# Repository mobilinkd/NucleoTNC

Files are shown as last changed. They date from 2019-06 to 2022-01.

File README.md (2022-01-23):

# NucleoTNC Firmware

Source code for STM32L432KC Nucleo32-based TNC (PCB & breadboard version).

http://www.mobilinkd.com/2019/06/24/nucleotnc/

# Building the Firmware

Use Eclipse with CDT and the GNU MCU Eclipse plugins.

If you are porting this to another build platform, you will need to
build the firmware using the same compiler and linker options.  As
with most firmware projects, there is a linker script with defines
the memory layout for for the Flash and SRAM.

## Blaze Dependency

There is a new dependency as of 2.4.3 with the addition of the Kalman
filter.  The firmware has a dependency on the Blaze C++ math library.

    mkdir blaze
    ln -s /usr/include/blaze blaze/

This also requires (for now) that the firmware be built with exceptions
enabled.

## Example GCC Command-line

Below are example compilation and linking lines for reference:

    arm-none-eabi-g++ -mcpu=cortex-m4 -mthumb -mfloat-abi=softfp -mfpu=fpv4-sp-d16 -O2 -fmessage-length=0 -fsigned-char -ffunction-sections -fdata-sections -fno-inline-functions -fsingle-precision-constant -fstack-usage -fstrict-aliasing -ffast-math -Wall -Wextra -Wlogical-op -Wfloat-equal -g -D__FPU_PRESENT=1 -DUSE_HAL_DRIVER -DARM_MATH_CM4 -DSTM32L432xx -D__weak=__attribute__((weak)) -DNUCLEOTNC=1 -I../Inc -I../Drivers/STM32L4xx_HAL_Driver/Inc -I/home/rob/workspace/Nucleo_L432KC_TNC/Inc -I/home/rob/workspace/Nucleo_L432KC_TNC/Drivers/STM32L4xx_HAL_Driver/Inc -I/home/rob/workspace/Nucleo_L432KC_TNC/Drivers/CMSIS/Include -I/home/rob/workspace/Nucleo_L432KC_TNC/Drivers/CMSIS/Device/ST/STM32L4xx/Include -I/home/rob/workspace/Nucleo_L432KC_TNC/Middlewares/Third_Party/FreeRTOS/Source/include -I/home/rob/workspace/Nucleo_L432KC_TNC/Middlewares/Third_Party/FreeRTOS/Source/CMSIS_RTOS -I/home/rob/workspace/Nucleo_L432KC_TNC/Middlewares/Third_Party/FreeRTOS/Source/portable/GCC/ARM_CM4F -I/home/rob/workspace/Nucleo_L432KC_TNC/TNC -I/usr/arm-none-eabi/include -std=gnu++1z -fabi-version=9 -fno-exceptions -fno-rtti -fno-use-cxa-atexit -fno-threadsafe-statics -Wno-register -c -o TNC/HdlcFrame.o ../TNC/HdlcFrame.cpp 
    arm-none-eabi-g++ -mcpu=cortex-m4 -mthumb -mfloat-abi=softfp -mfpu=fpv4-sp-d16 -O2 -fmessage-length=0 -fsigned-char -ffunction-sections -fdata-sections -fno-inline-functions -fsingle-precision-constant -fstack-usage -fstrict-aliasing -ffast-math -Wall -Wextra -Wlogical-op -Wfloat-equal -g -T /home/rob/workspace/Nucleo_L432KC_TNC/STM32L432KC_FLASH.ld -Xlinker --gc-sections -Wl,-Map,firmware.map --specs=nano.specs -o firmware.elf Drivers/STM32L4xx_HAL_Driver/Src/stm32l4xx_hal.o Drivers/STM32L4xx_HAL_Driver/Src/stm32l4xx_hal_adc.o Drivers/STM32L4xx_HAL_Driver/Src/stm32l4xx_hal_adc_ex.o Drivers/STM32L4xx_HAL_Driver/Src/stm32l4xx_hal_cortex.o Drivers/STM32L4xx_HAL_Driver/Src/stm32l4xx_hal_crc.o Drivers/STM32L4xx_HAL_Driver/Src/stm32l4xx_hal_crc_ex.o Drivers/STM32L4xx_HAL_Driver/Src/stm32l4xx_hal_dac.o Drivers/STM32L4xx_HAL_Driver/Src/stm32l4xx_hal_dac_ex.o Drivers/STM32L4xx_HAL_Driver/Src/stm32l4xx_hal_dma.o Drivers/STM32L4xx_HAL_Driver/Src/stm32l4xx_hal_dma_ex.o Drivers/STM32L4xx_HAL_Driver/Src/stm32l4xx_hal_flash.o Drivers/STM32L4xx_HAL_Driver/Src/stm32l4xx_hal_flash_ex.o Drivers/STM32L4xx_HAL_Driver/Src/stm32l4xx_hal_flash_ramfunc.o Drivers/STM32L4xx_HAL_Driver/Src/stm32l4xx_hal_gpio.o Drivers/STM32L4xx_HAL_Driver/Src/stm32l4xx_hal_i2c.o Drivers/STM32L4xx_HAL_Driver/Src/stm32l4xx_hal_i2c_ex.o Drivers/STM32L4xx_HAL_Driver/Src/stm32l4xx_hal_opamp.o Drivers/STM32L4xx_HAL_Driver/Src/stm32l4xx_hal_opamp_ex.o Drivers/STM32L4xx_HAL_Driver/Src/stm32l4xx_hal_pwr.o Drivers/STM32L4xx_HAL_Driver/Src/stm32l4xx_hal_pwr_ex.o Drivers/STM32L4xx_HAL_Driver/Src/stm32l4xx_hal_rcc.o Drivers/STM32L4xx_HAL_Driver/Src/stm32l4xx_hal_rcc_ex.o Drivers/STM32L4xx_HAL_Driver/Src/stm32l4xx_hal_rng.o Drivers/STM32L4xx_HAL_Driver/Src/stm32l4xx_hal_rtc.o Drivers/STM32L4xx_HAL_Driver/Src/stm32l4xx_hal_rtc_ex.o Drivers/STM32L4xx_HAL_Driver/Src/stm32l4xx_hal_tim.o Drivers/STM32L4xx_HAL_Driver/Src/stm32l4xx_hal_tim_ex.o Drivers/STM32L4xx_HAL_Driver/Src/stm32l4xx_hal_uart.o Drivers/STM32L4xx_HAL_Driver/Src/stm32l4xx_hal_uart_ex.o Middlewares/Third_Party/FreeRTOS/Source/CMSIS_RTOS/cmsis_os.o Middlewares/Third_Party/FreeRTOS/Source/croutine.o Middlewares/Third_Party/FreeRTOS/Source/event_groups.o Middlewares/Third_Party/FreeRTOS/Source/list.o Middlewares/Third_Party/FreeRTOS/Source/portable/GCC/ARM_CM4F/port.o Middlewares/Third_Party/FreeRTOS/Source/portable/MemMang/heap_4.o Middlewares/Third_Party/FreeRTOS/Source/queue.o Middlewares/Third_Party/FreeRTOS/Source/tasks.o Middlewares/Third_Party/FreeRTOS/Source/timers.o Src/arm_fir_f32.o Src/arm_fir_fast_q15.o Src/arm_fir_init_f32.o Src/arm_fir_init_q15.o Src/arm_fir_interpolate_init_q15.o Src/arm_fir_interpolate_q15.o Src/arm_offset_q15.o Src/arm_q15_to_float.o Src/freertos.o Src/main.o Src/stm32l4xx_hal_msp.o Src/stm32l4xx_hal_timebase_TIM.o Src/stm32l4xx_it.o Src/system_stm32l4xx.o TNC/AFSKModulator.o TNC/AFSKTestTone.o TNC/Afsk1200Demodulator.o TNC/AfskDemodulator.o TNC/AudioInput.o TNC/AudioLevel.o TNC/DCD.o TNC/Demodulator.o TNC/FilterCoefficients.o TNC/Fsk9600Demodulator.o TNC/Fsk9600Modulator.o TNC/Goertzel.o TNC/Golay24.o TNC/HdlcDecoder.o TNC/HdlcFrame.o TNC/IOEventTask.o TNC/Kiss.o TNC/KissHardware.o TNC/KissTask.o TNC/LEDIndicator.o TNC/Log.o TNC/M17.o TNC/M17Demodulator.o TNC/M17Encoder.o TNC/M17Modulator.o TNC/ModulatorTask.o TNC/NullPort.o TNC/PortInterface.o TNC/SerialPort.o newlib/_exit.o newlib/_sbrk.o newlib/_syscalls.o startup/startup_stm32l432xx.o 

All of the macros defined on the compiler line are important in order
to properly build the firmware.

# Installing firmware

Firmware can be installed via the storage interface (drag & drop), the
on-board ST/LINK port, or via USB DFU.

## Drag & Drop

For the NucleoTNC, the easiest way to install firmware is to copy the
firmware file to the TNC directly.  The NucleoTNC will show up as a storage
device when plugged in.  Just copy the firmware.bin file into the shared
folder.  The firmware will automatically install, the NucleoTNC will reset,
and the new firmware will be running.

## ST/Link

The ST/Link port is a debug port exposed by the NucleoTNC.  It can be used
by Eclipse and other IDEs to directly upload the firmware to the TNC.

## USB DFU

 1. Download the STM32CubeProgrammer.
    https://s3.amazonaws.com/mobilinkd/en.stm32cubeprog-1.4.0.zip
    This programmer will work on Linux, OS X, and Windows.

 2. Download the ELF file from the release (or that you have built from source).

 3. Run the STM32CubeProgrammer from the command-line. (Replace "firmware.elf" with the appropriate firmware filename.)

    ./STM32_Programmer_CLI -c port=USB1 -d firmware.elf -v -g 0x8000000

 4. When that is complete, the NucleoTNC will restart with the new firmware.

----

## Important Note
If you regenerate the STM32 code, please note that the LL ADC driver in
the 1.12.0 version of the HAL driver is buggy.

   Drivers/STM32L4xx_HAL_Driver/Inc/stm32l4xx_ll_adc.h

This file has been modified to address the defect.  If it is replaced by
STM32CubeMX, please ensure that the defect has been fixed.

Details of the defect are available [on the ST community site](https://community.st.com/s/question/0D50X00009bLP0eSAG/adc-init-bug-with-optimization-o1-stm32l4 ADC init bug with optimization >= -O1).

----

## TNC Build Instructions

Please go here: [TNC Build Instructions](Build/NucleoTNC.ipynb)

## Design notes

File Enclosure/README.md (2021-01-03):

# NucleoTNC Enclosure

This work is licensed under a
<a rel="license" href="http://creativecommons.org/licenses/by-sa/4.0/">
Creative Commons Attribution-ShareAlike 4.0 International License</a>.
<a rel="license" href="http://creativecommons.org/licenses/by-sa/4.0/">
</a><br />

Please attribute the work to *Rob Riggs, WX9O, Mobilinkd LLC*.

This is an enclosure for the NucleoTNC PCB.  It uses a two-part extruded
aluminum enclosure, SZOMK AK-C-C15 (26*71*100mm).  This folder contains
the faceplates for the enclosure.  These are KiCAD components for the
front and read faceplates.  It also includes a spacer designed to raise
the Nucleo32 board from the PCB so that it will fit into the enclosure.

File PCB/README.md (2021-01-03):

# NucleoTNC PCB

This directory contains the KiCAD files for the Nucleo TNC PCB.  This is a PCB
for the [NucleoTNC breadboard project](http://www.mobilinkd.com/2019/06/24/nucleotnc/).

The design goal was to allow experimenters to take their breadboard project and give
it a more permanent home on a real printed circuit board.

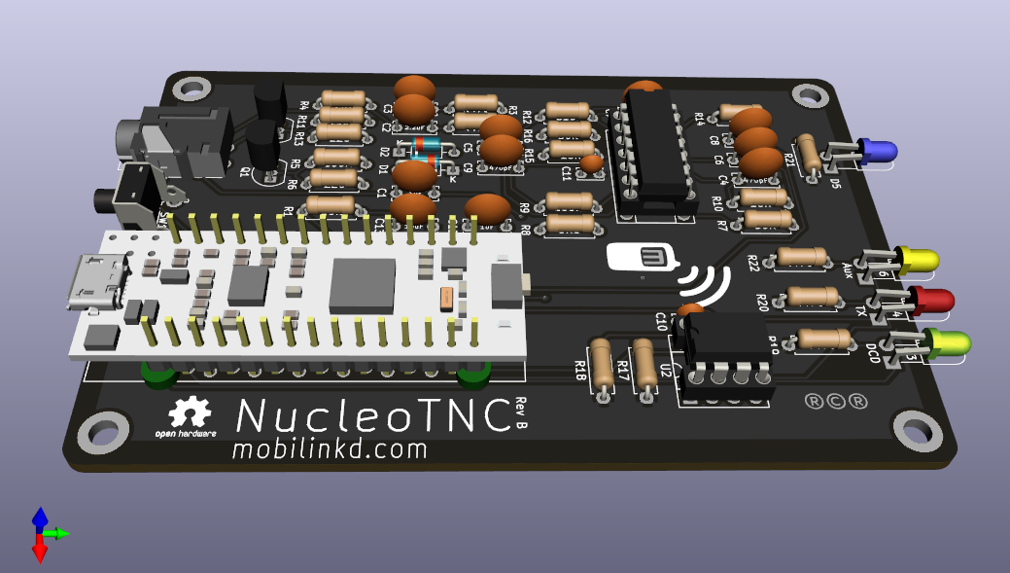
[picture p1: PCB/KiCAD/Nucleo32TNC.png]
NucleoTNC PCB


This PCB is designed to fit in the [enclosure](../Enclosure/README.md) that is also
available in this repository.

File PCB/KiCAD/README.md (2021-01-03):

# NucleoTNC PCB

This work is licensed under a
<a rel="license" href="http://creativecommons.org/licenses/by-sa/4.0/">
Creative Commons Attribution-ShareAlike 4.0 International License</a>.
<a rel="license" href="http://creativecommons.org/licenses/by-sa/4.0/">
</a><br />

Please attribute the work to *Rob Riggs, WX9O, Mobilinkd LLC*.

This directory contains the KiCAD files for the Nucleo TNC printed circuit
board (PCB).  This is a PCB for the [NucleoTNC breadboard project](http://www.mobilinkd.com/2019/06/24/nucleotnc/).

NucleoTNC PCB

The design goal is to allow experimenters to take their breadboard project
and give it a more permanent home on a real printed circuit board.

This PCB is designed to fit in the [enclosure](../../Enclosure/README.md) that is
also available in this repository.

Please refer to the [NucleoTNC breadboard project](https://nbviewer.jupyter.org/github/mobilinkd/NucleoTNC/blob/master/Build/NucleoTNC.ipynb)
project for in-depth discussion of the design and theory of operation.  We are
only going to cover briefly the design differences below, then provide the full
bill of materials (BOM) required to build the TNC.

This repository also contains the open source firmware for the TNC.  The
Mobilinkd project on Github contains numerous other resources, including a
Python-based configuration program.

These PCBs can be purchased directly from the mobilinkd store.

https://store.mobilinkd.com/collections/kits

## Breadboard Differences

This section covers the differences between the NucleoTNC breadboard project
and the PCB version.  The schematic is presented below.

There are a few small differences in design.

The one necessary change was to the 3.5mm jack.  The breadboard module is
inappropriate for a PCB design.  The PCB uses a CUI SJ-43515TS or SJ-43514
jack.  Discovered after this choice was made is that CUI uses the same model
number for both a through-hole component and a surface mount component.  For
this project you will need the through-hole part.

IC sockets for the quad op-amp and EEPROM are recommended.  Insert the ICs
into the sockets rather than soldering these components directly on the PCB.

There are two additional LEDs on the PCB.  One indicates power.  The other
is there as an auxilliary indicator and is currently unused.  These exist
because the power LED and auxilliary LED on the Nucleo32 board are hidden
when the PCB is mounted in an enclosure.  Each require a 470 Ohm resistor.

There is an external reset button.  This is because the reset switch on the
TNC is inaccessible when mounted in an enclosure.  The reset button is a
C&K PTS645VL58-2 LFS.

And there are two additional capacitors on the power plane for added
decoupling.  These are not strictly necessary.

We have changed the input coupling capacitor from 0.22uF to 1uF to improve
the low frequency response of the TNC.  This is now recommended for the
breadboard version as well.

Included in the enclosure components is a spacer PCB.  This can be 3D-printed
rather than made out of FR-4 PCB material.  Two of these are needed to raise
the Nucleo32 board off the PCB so that it will fit in the enclosure properly.
You can see the two spacers in the rendering at the top of the page.

The through-holes for the Nucleo board on the PCB are staggered.  This allows
for a press-fit of the Nucleo board into the PCB for testing.  The Nucleo32 can
be inserted into the PCB and should work without being soldered in.  It will
likely only work for a few insertions.  And the Nucleo board should be soldered
in place before installing it into the enclosure.  If it comes out of the
PCB while power is applied, there is risk of damage to the Nucleo board and
the components on the PCB.

NucleoTNC PCB Schematic

## Bill of Materials

| Manufacturer 	| Manufacturer Part Number 	| Description 	| Quantity 	| Unit Price 	| Extended Price 	|
|---	|---	|---	|---	|---	|---	|
| CUI 	| SJ-43515TS 	| TRRS 3.5MM JACK THROUGH-HOLE  	| 1 	| 1.08 	| 1.08 	|
| Vishay Semiconductor Diodes Division 	| BAT85S-TAP 	| DIODE SCHOTTKY 30V 200MA DO35 	| 2 	| 0.38 	| 0.76 	|
| STMicroelectronics 	| NUCLEO-L432KC 	| NUCLEO-32 STM32L432KC EVAL BRD 	| 1 	| 10.99 	| 10.99 	|
| Microchip Technology 	| MCP6004-I/P 	| IC OPAMP GP 4 CIRCUIT 14DIP 	| 1 	| 0.45 	| 0.45 	|
| Microchip Technology 	| 24LC32A-I/P 	| IC EEPROM 32K I2C 400KHZ 8DIP 	| 1 	| 0.41 	| 0.41 	|
| Microchip Technology 	| 2N7000-G 	| MOSFET N-CH 60V 0.2A TO92-3 	| 2 	| 0.38 	| 0.76 	|
| Broadcom Limited 	| HLMP-1301 	| LED RED DIFFUSED T-1 T/H 	| 1 	| 0.41 	| 0.41 	|
| Broadcom Limited 	| HLMP-1503 	| LED GREEN DIFFUSED T-1 T/H 	| 1 	| 0.41 	| 0.41 	|
| Stackpole Electronics Inc 	| RNF18FTD100K 	| RES 100K OHM 1/8W 1% AXIAL 	| 3 	| 0.1 	| 0.30 	|
| Stackpole Electronics Inc 	| RNF14FTD10K0 	| RES 10K OHM 1/4W 1% AXIAL 	| 1 	| 0.1 	| 0.10 	|
| Stackpole Electronics Inc 	| RNMF14FTC510R 	| RES 510 OHM 1/4W 1% AXIAL 	| 2 	| 0.1 	| 0.20 	|
| Stackpole Electronics Inc 	| RNMF14FTC6K80 	| RES 6.8K OHM 1/4W 1% AXIAL 	| 1 	| 0.1 	| 0.10 	|
| Stackpole Electronics Inc 	| RNF14FTD470R 	| RES 470 OHM 1/4W 1% AXIAL 	| 6 	| 0.1 	| 0.60 	|
| Stackpole Electronics Inc 	| RNMF14FTC220R 	| RES 220 OHM 1/4W 1% AXIAL 	| 2 	| 0.1 	| 0.20 	|
| Stackpole Electronics Inc 	| RNMF14FTC2K20 	| RES 2.2K OHM 1/4W 1% AXIAL 	| 3 	| 0.1 	| 0.30 	|
| Stackpole Electronics Inc 	| RNMF14FTC16K0 	| RES 16K OHM 1/4W 1% AXIAL 	| 2 	| 0.1 	| 0.20 	|
| Stackpole Electronics Inc 	| RNMF14FTC30K0 	| RES 30K OHM 1/4W 1% AXIAL 	| 2 	| 0.1 	| 0.20 	|
| Vishay BC Components 	| K471J15C0GF53L2 	| CAP CER 470PF 50V C0G/NP0 RADIAL 	| 2 	| 0.22 	| 0.44 	|
| AVX Corporation 	| SR201A102JAR 	| CAP CER 1000PF 100V C0G/NP0 RAD  	| 2 	| 0.29 	| 0.58 	|
| Vishay BC Components 	| K103M15X7RF53L2 	| CAP CER 10000PF 50V X7R RADIAL 	| 1 	| 0.21 	| 0.21 	|
| AVX Corporation 	| SR215C104KAA 	| CAP CER 0.1UF 50V X7R RADIAL 	| 2 	| 0.2 	| 0.40 	|
| TDK Corporation 	| FG28X7R1A225KRT06 	| CAP CER 2.2UF 10V X7R RADIAL 	| 1 	| 0.34 	| 0.34 	|
| Broadcom Limited‎ 	| HLMP-1401 	| LED YELLOW DIFFUSED T-1 T/H | 1 	| 0.49 	| 0.49 	|
| Kingbright‎ 	| WP710A10QBC/D 	| LED BLUE CLEAR T-1 T/H | 1 	| 0.44 	| 0.44 	|
| C&K 	| PTS645VL58-2 LFS 	| SWITCH TACTILE SPST-NO 0.05A 12V 	| 1 	| 0.27 	| 0.27 	|
| TDK Corporation | FG28X7R1E105KRT06 | CAP CER 1UF 25V X7R RADIAL | 2 | 0.32 | 0.64 |
| TDK Corporation | FG24X7R1A106KRT06 | CAP CER 10UF 10V X7R RADIAL | 1 | 0.58 | 0.58 |
| On Shore Technology Inc. | ED14DT | CONN IC DIP SOCKET 14POS TIN | 1 | 0.18 | 0.18 |
| On Shore Technology Inc. | ED08DT | CONN IC DIP SOCKET 8POS TIN | 1 | 0.16 | 0.16 |

The new items are the last 6 items on the list.  There are two additional 470 Ohm resister (6 instead of 4) in the BOM.

You can explore the PCB via an [interactive BOM](https://htmlpreview.github.io/?https://github.com/mobilinkd/NucleoTNC/blob/master/PCB/KiCAD/bom/ibom.html).
Please note that it does not show the two DIP sockets.

## Equipment

You will need the following equipment to assemble, test and use the TNC.

 1. Soldering Iron
 1. Solder (preferrably 0.5mm rosin core)
 1. A digital multi-meter (DMM) with Voltage, Resistance, Continuity, Diode
    and Capacitance testing capabiility. (Something like an ANENG AN8008
    will work.)
 1. Anti-static mat and wrist strap.
 1. A micro-USB cable.
 1. A computer running Linux, OS X, or Windows 10.
 1. A 2mm hex driver or allen wrench if you are building the enclosure.

## Assembly

Assemble the items on a grounded anti-static mat.

Use the [interactive BOM](https://htmlpreview.github.io/?https://github.com/mobilinkd/NucleoTNC/blob/master/PCB/KiCAD/bom/ibom.html)
(use ctrl-click on the link to open it in another tab).  Install the items in
the order listed on the interactive BOM.  This makes it easier to solder
multiple components to the board without having them fall out, because the
BOM is sorted roughly by component height.

**The diodes, ICs, MOSFETs and Nucleo32 module are easily damaged by
electro-static discharge.  Use an anti-static wrist strap that is well-grounded
when handling the diodes, ICs, MOSFETs and Nucleo32 module, and when handling
the PCB after these items have been installed.**

When it comes to installing the two ICs, U1 and U2, install the IC sockets
only.  Install the ICs into the sockets after the reset switch has been
soldered to the board.

The final step is to install the Nucleo32 board.  Place the two spacers across
the pairs of pins on either end of the module.  It may be easier to place the
PCB on its side when inserting the module to keep the spacers from falling
off.  The pins are staggered.  It should require a little bit of force to get
the module inserted.  Once inserted, the pins should make solid contact with
the PCB -- solid enough for initial testing.

## Testing

**Note: when inserting a USB cable into the Nucleo32 module, make sure that
the USB cable does not apply any torque to the module as this can negatively
affect the press-fit connection with the PCB.**

We are going to connect the TNC to the computer via USB.  Plug the micro-USB
cable into the computer.

Insert a USB cable into the Nucleo32 module.  You should see the blue LED
light up.  This indicates that the board is powered.

You should also see a drive mounted on the computer and a USB serial port
created.

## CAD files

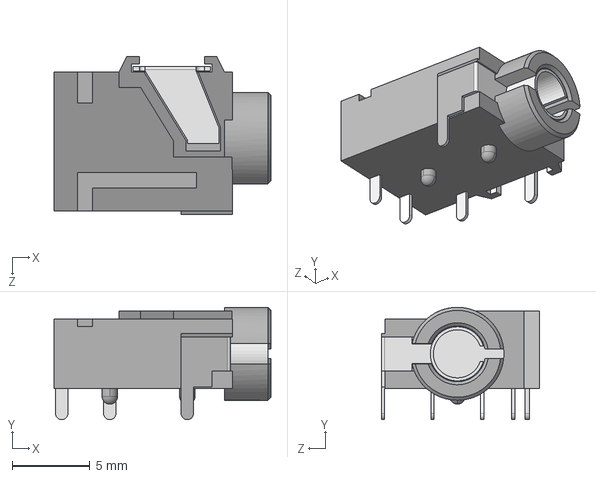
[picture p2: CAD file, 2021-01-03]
PCB/KiCAD/CUI_DEVICES_SJ-43515TS.step
14.0 x 7.25 x 10.2 mm

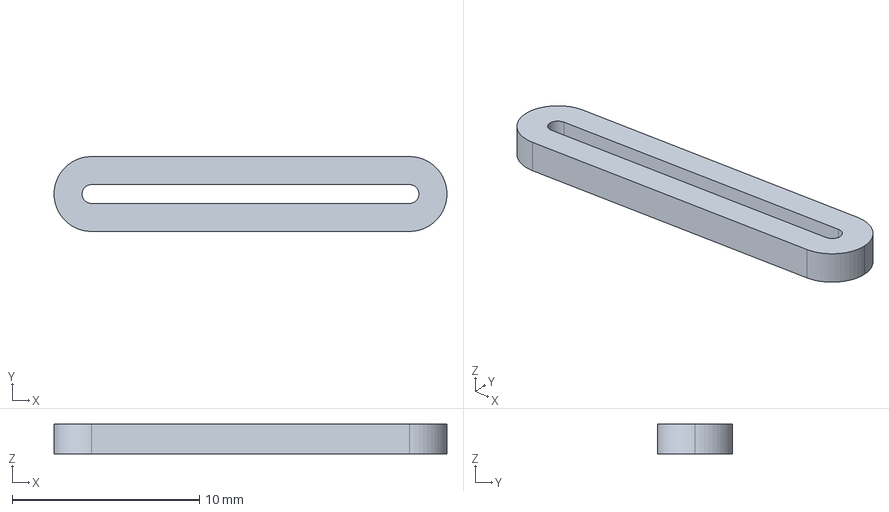
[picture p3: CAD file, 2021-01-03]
PCB/KiCAD/Spacer.step
21.0 x 4.00 x 1.60 mm

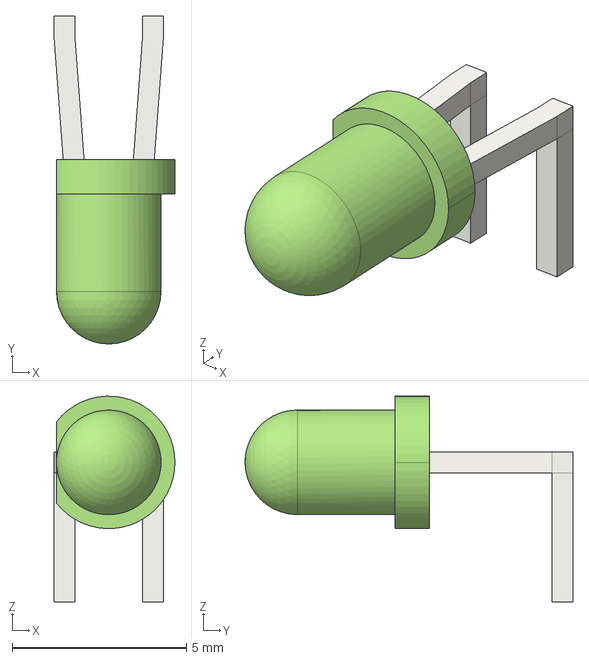
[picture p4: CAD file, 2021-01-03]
PCB/KiCAD/led_green.step
3.47 x 9.41 x 5.90 mm

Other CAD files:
PCB/KiCAD/led_blue.step
PCB/KiCAD/led_red.step
PCB/KiCAD/led_yellow.step

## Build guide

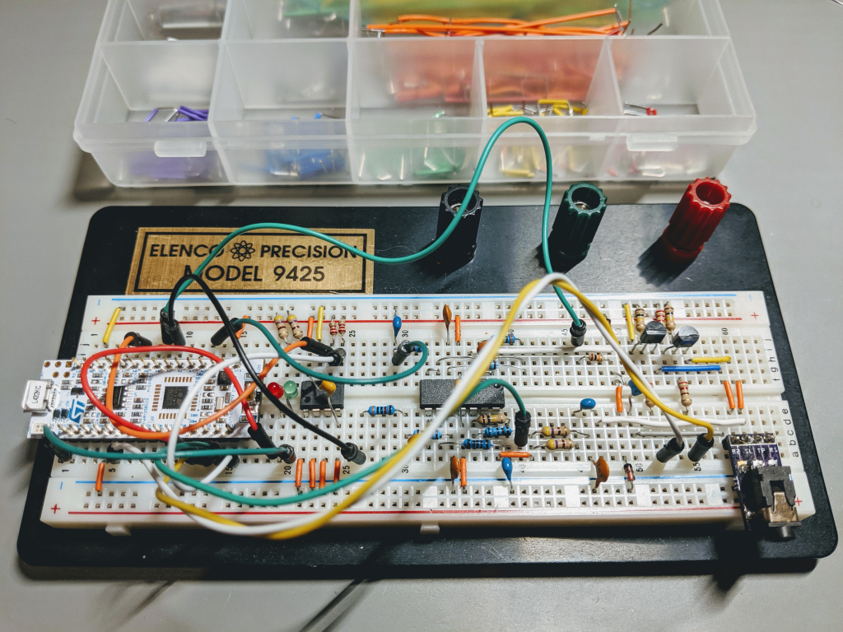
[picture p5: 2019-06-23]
Build/AssemblyStep10.png

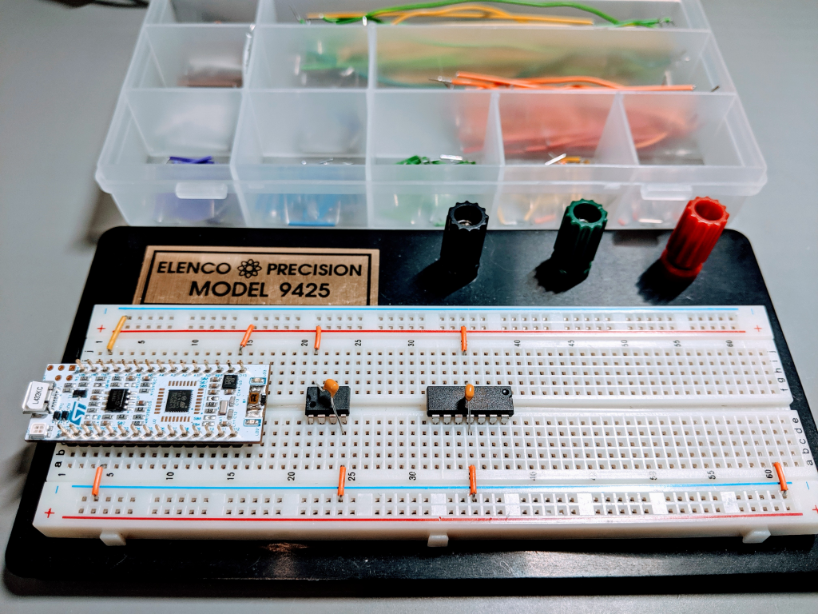
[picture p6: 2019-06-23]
Build/AssemblyStep3.png

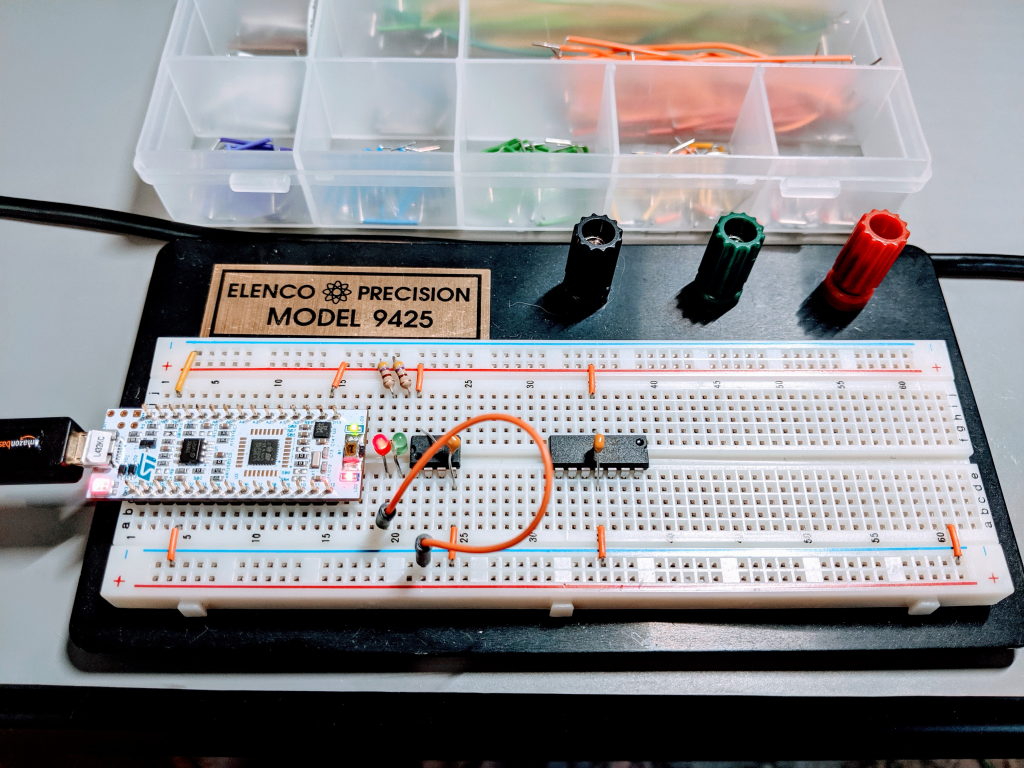
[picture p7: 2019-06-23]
Build/AssemblyStep4.png

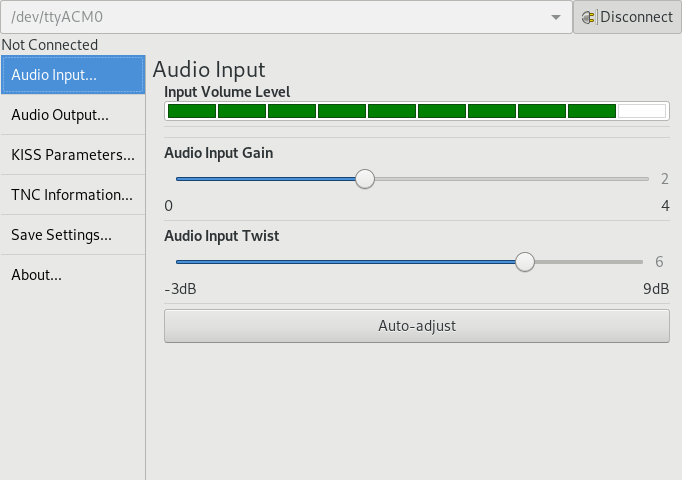
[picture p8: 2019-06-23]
Build/TncConfigApp-Input.png

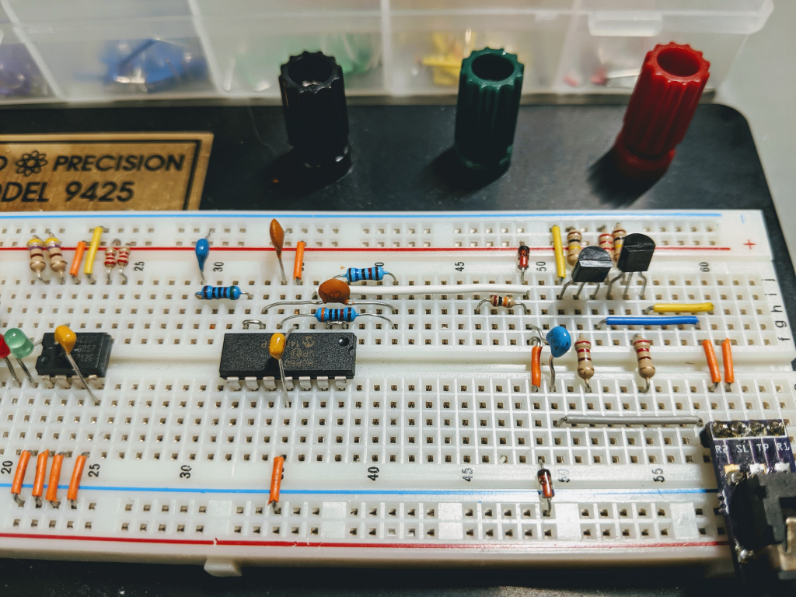
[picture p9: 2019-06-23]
Build/AssemblyStep8-bad.png

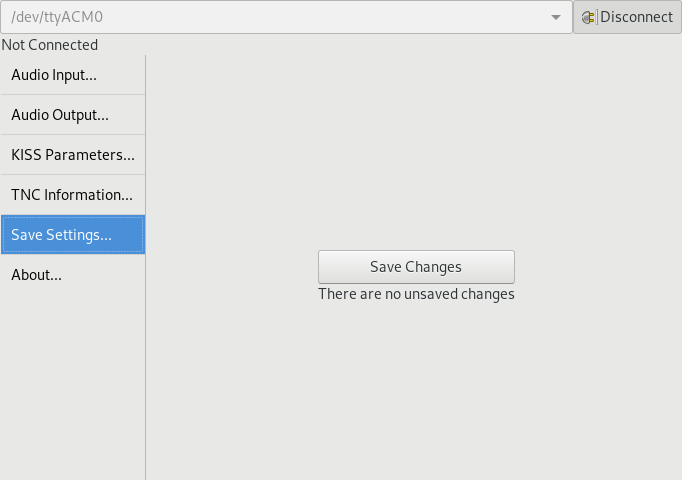
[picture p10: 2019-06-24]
Build/TncConfigApp-Save.png

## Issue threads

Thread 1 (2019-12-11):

Serial communication with TNC does not work

phaethon, 2019-12-11:
I have built TNC on a breadboard (version with STM32L432KC). Uploaded firmware (firmware.bin) and tried to connect with tnc1-python-config. It allows to connect to device, the button Connect changes to Disconnect, but in the upper left corner it still says "Not connected" and all fields seem to be set to default values (e.g. TNC Information shows "Uknown" and "Unsupported").

Rebuilt firmware from source and started debugging with gdb. It seems to be initializing normally, then getting into a loop analyzing audio. I enabled define KISS_LOGGING and got some meaningful debug output on the serial console. This is the start of it:
```
�Mobilinkd Nucleo32 Breadboard TNC versi�CPU core clock: 48000000Hz��    Device UID: 0029004B 374B500C 2038325�Bootloader version: 0x10��Loading settings from EEPROM��Attempting to read 812 bytes from EEPRO�Hardware Settings (size=812):��TX Delay: 30��P* Persistence: 64��Slot Time: 10��TX Tail: 1��Duplex: 0��Modem Type: 1��TX Gain: 63��RX Gain: 0��TX Twist: 50��RX Twist: 0��Log Level: 0��Options: 16��MYCALL: NOCALL��Dedupe time (secs): 30��Aliases:��Beacons:��Checksum: 53ees��Setting output gain: 63 (log 0 + 1013)��Setting input gain: 0��enter readLevels��readLevels: start��exit readLevels��Vpp = 6, Vavg = 7114��Vmin = 7111, Vmax = 7117��DEMODULATOR��enter demodulatorTask��Acquired frame 0x20004514 (size after �Acquired frame 0x20004538 (size after �Acquired frame 0x2000455c (size after �FCS = e77e��CRC = f622�� ```

Tried to place breakpoints in all serial port callbacks, but they don't fire neither using tnc1-python-config nor when connecting with serial console and trying to send keystrokes.

Thanks in advance!

mobilinkd, 2019-12-12:
Please use the Mobilinkd list at https://groups.io/g/mobilinkd for support with this TNC.

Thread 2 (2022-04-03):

schematic for PCB rev. C

VR2XKP, 2022-04-03:
Hello

Although the BOM was updated to rev C. but the schematic is still ver. B only. A diode was added but I cannot track the connection via the BOM.

Does it possible to provide the rev C schematic as well?

BR
VR2XKP

phantum29, 2023-01-22:
I was taken back by the added diode as well. Also, it was not listed in the BOM or on the interactive BOM page. Fortunately, I have more on hand but I'd like to review the schematic as well, as well as any reference to the design changes in rev C too. Kinda surprised, or maybe I just simply overlooked it, as the OP is from over 9 months ago.

Thanks!

Ser-Zile, 2024-04-17:
I’d like to bump this. Master branch has 2 sets of schematics, but I can’t find the rev. C. I’m planning on building locally pcb due to insane shipping costs to my location…

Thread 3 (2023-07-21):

The PCB design files are not present in the KiCAD folder

DeflateAwning, 2023-07-21:

DeflateAwning, 2023-07-21:
Never mind. The folder structure is a bit confusing with `/KiCAD` and `/PCB/KiCAD` both containing very similar files, but only one of them actually containing a PCB design. I guess it makes enough sense now

Closed 2023-07-21.

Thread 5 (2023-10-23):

Feature Request: TX Watchdog Timer

ben-kuhn, 2023-10-23:
I occasionally run in to an issue where the TNC will get stuck in TX and need to be reset.  I'm reasonably sure this is due to RFI somewhere, but I've never been able to track it down and no amount of ferrite beads help.  It happens on my mobilinkd as well as several NucleoTNCs.  The documentation suggesting ferrite beads on the cable between the radio and TNC suggest I'm not the first to see this.  My current work-around is a TOT set on the radio, but the TNC still needs to be reset once entering this condition.

As a workaround, and for HT use, etc... where rf conditions may be out of the user's control, it would be a nice feature to have a user-configurable TX watchdog timer to reset the TNC after a user-defined period of time in TX--user defined so it doesn't mess with M17 voice QSOs.

Thanks for your consideration.

mobilinkd, 2023-10-25:
Does pressing the reset button on the TNC when it hits this condition stop
the radio from transmitting?

Kind Regards,

Rob Riggs WX9O
Mobilinkd LLC

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

ben-kuhn, 2023-10-26:
I will let you know next time I see this happen.

mobilinkd, 2023-10-29:
Ok, thanks.

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

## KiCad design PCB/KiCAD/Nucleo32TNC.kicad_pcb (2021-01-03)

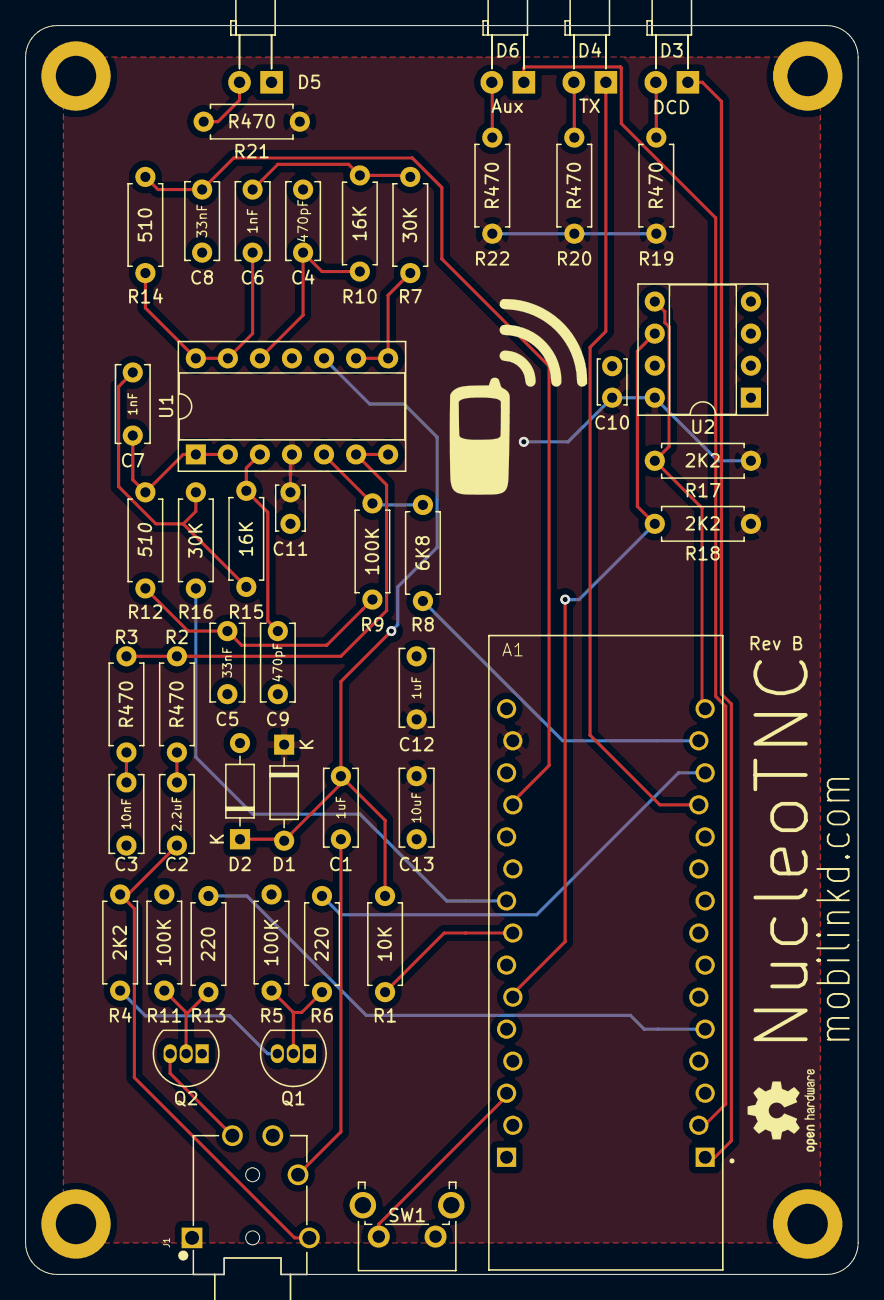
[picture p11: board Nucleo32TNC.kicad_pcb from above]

Board: 2 copper layers, 66.0 x 99.0 mm, 53 parts (0 on the bottom side), 37 nets.

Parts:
A1: NUCLEO-L432KC; MODULE_NUCLEO-L432KC
C1, C12: 1uF; C_Disc_D6.0mm_W2.5mm_P5.00mm
C2: 2.2uF; C_Disc_D6.0mm_W2.5mm_P5.00mm
C3: 10nF; C_Disc_D6.0mm_W2.5mm_P5.00mm
C4, C9: 470pF; C_Disc_D6.0mm_W2.5mm_P5.00mm
C5, C8: 33nF; C_Disc_D6.0mm_W2.5mm_P5.00mm
C6, C7: 1nF; C_Disc_D6.0mm_W2.5mm_P5.00mm
C10, C11: 0.1uF; C_Disc_D3.4mm_W2.1mm_P2.50mm
C13: 10uF; C_Disc_D6.0mm_W2.5mm_P5.00mm
D1, D2: BAT85; D_DO-35_SOD27_P7.62mm_Horizontal
D3: DCD; LED_D3.0mm_Horizontal_O3.81mm_Z2.0mm
D4: TX; LED_D3.0mm_Horizontal_O3.81mm_Z2.0mm
D5: BLU LED; LED_D3.0mm_Horizontal_O3.81mm_Z2.0mm
D6: Aux; LED_D3.0mm_Horizontal_O3.81mm_Z2.0mm
G1: LOGO
H1, H2, H3, H4: MountingHole; MountingHole_3.2mm_M3_ISO14580_Pad
J1: SJ-43515TS; CUI_SJ-43515TS
Q1, Q2: 2N7000; TO-92_Inline
R1: 10K; R_Axial_DIN0207_L6.3mm_D2.5mm_P7.62mm_Horizontal
R2, R3, R19, R20, R21, R22: R470; R_Axial_DIN0207_L6.3mm_D2.5mm_P7.62mm_Horizontal
R4, R17, R18: 2K2; R_Axial_DIN0207_L6.3mm_D2.5mm_P7.62mm_Horizontal
R5, R9, R11: 100K; R_Axial_DIN0207_L6.3mm_D2.5mm_P7.62mm_Horizontal
R6, R13: 220; R_Axial_DIN0207_L6.3mm_D2.5mm_P7.62mm_Horizontal
R7, R16: 30K; R_Axial_DIN0207_L6.3mm_D2.5mm_P7.62mm_Horizontal
R8: 6K8; R_Axial_DIN0207_L6.3mm_D2.5mm_P7.62mm_Horizontal
R10, R15: 16K; R_Axial_DIN0207_L6.3mm_D2.5mm_P7.62mm_Horizontal
R12, R14: 510; R_Axial_DIN0207_L6.3mm_D2.5mm_P7.62mm_Horizontal
SW1: PTS645VL58-2 LFS; SW_Tactile_SPST_Angled_PTS645Vx58-2LFS
U1: MCP6004; DIP-14_W7.62mm_Socket
U2: 24LC32; DIP-8_W7.62mm_Socket

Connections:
+3V3: A1.4.14, C10.1, C11.1, C12.1, C13.1, D1.1, R17.1, R18.1, R19.1, R20.1, R21.1, R22.1, U1.4, U2.8
/ADC_AUDIO: A1.4.12, C8.2, R14.1
/AUDIO_ATTEN: A1.3.14, R8.2
/AUDIO_IN: C1.2, J1.T
/AUDIO_OUT: C2.1, J1.R2, R4.2
/DAC_AUDIO: A1.4.9, R16.2
/DC_OFFSET: A1.4.8, R1.2
/I2C_SCL: A1.4.6, R18.2, U2.6
/I2C_SDA: A1.3.15, R17.2, U2.5
/LED_DCD: A1.3.1, D3.1
/LED_MISC: A1.3.2, D6.1
/LED_TX: A1.3.12, D4.1
/PTT: J1.R1, Q2.3
/PTT_MULTIPLEX: A1.3.13, R6.1
/PTT_SIMPLEX: A1.3.5, R13.1
GND: A1.3.4, A1.4.2, C3.1, C4.1, C5.1, C8.1, C9.1, C10.2, C11.2, C12.2, C13.2, D2.2, D5.1, H1.1, H2.1, H3.1, H4.1, J1.S, Q1.1, Q2.1, R5.2, R11.2, SW1.1, U1.11, U2.1, U2.2, U2.3, U2.4, U2.7
unnamed: A1.4.3, SW1.2
unnamed: C1.1, D1.2, D2.1, R1.1, U1.10
unnamed: C2.2, R2.2
unnamed: C3.2, R3.2
unnamed: C4.2, R10.1, U1.12
unnamed: C5.2, R9.1, R12.2
unnamed: C6.1, R14.2, U1.13, U1.14
unnamed: C6.2, R7.1, R10.2
unnamed: C7.1, R15.1, R16.1
unnamed: C7.2, R12.1, U1.1, U1.2
unnamed: C9.2, R15.2, U1.3
unnamed: D3.2, R19.2
unnamed: D4.2, R20.2
unnamed: D5.2, R21.2
unnamed: D6.2, R22.2
unnamed: Q1.2, R5.1, R6.2
unnamed: Q1.3, R4.1
unnamed: Q2.2, R11.1, R13.2
unnamed: R2.1, R3.1, U1.6, U1.7
unnamed: R7.2, U1.8, U1.9
unnamed: R8.1, R9.2, U1.5

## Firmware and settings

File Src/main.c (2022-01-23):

/**
  ******************************************************************************
  * @file           : main.c
  * @brief          : Main program body
  ******************************************************************************
  * This notice applies to any and all portions of this file
  * that are not between comment pairs USER CODE BEGIN and
  * USER CODE END. Other portions of this file, whether 
  * inserted by the user or by software development tools
  * are owned by their respective copyright owners.
  *
  * Copyright (c) 2021 STMicroelectronics International N.V. 
  * All rights reserved.
  *
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
  ******************************************************************************
  */
/* Includes ------------------------------------------------------------------*/
#include "main.h"
#include "stm32l4xx_hal.h"
#include "cmsis_os.h"

/* USER CODE BEGIN Includes */
#include "LEDIndicator.h"
#include "Log.h"
#include <stdint.h>
/* USER CODE END Includes */

ADC_HandleTypeDef hadc1;
DMA_HandleTypeDef hdma_adc1;

CRC_HandleTypeDef hcrc;

DAC_HandleTypeDef hdac1;
DMA_HandleTypeDef hdma_dac_ch1;

I2C_HandleTypeDef hi2c3;
DMA_HandleTypeDef hdma_i2c3_rx;
DMA_HandleTypeDef hdma_i2c3_tx;

OPAMP_HandleTypeDef hopamp1;

IWDG_HandleTypeDef hiwdg;

RNG_HandleTypeDef hrng;

RTC_HandleTypeDef hrtc;

TIM_HandleTypeDef htim1;
TIM_HandleTypeDef htim6;
TIM_HandleTypeDef htim7;

UART_HandleTypeDef huart2;
DMA_HandleTypeDef hdma_usart2_rx;
DMA_HandleTypeDef hdma_usart2_tx;

osThreadId defaultTaskHandle;
uint32_t defaultTaskBuffer[ 256 ];
osStaticThreadDef_t defaultTaskControlBlock;
osThreadId ioEventTaskHandle;
uint32_t ioEventTaskBuffer[ 384 ];
osStaticThreadDef_t ioEventTaskControlBlock;
osThreadId audioInputTaskHandle;
uint32_t audioInputTaskBuffer[ 512 ];
osStaticThreadDef_t audioInputTaskControlBlock;
osThreadId modulatorTaskHandle;
uint32_t modulatorTaskBuffer[ 384 ];
osStaticThreadDef_t modulatorTaskControlBlock;
osMessageQId ioEventQueueHandle;
uint8_t ioEventQueueBuffer[ 16 * sizeof( uint32_t ) ];
osStaticMessageQDef_t ioEventQueueControlBlock;
osMessageQId serialInputQueueHandle;
uint8_t serialInputQueueBuffer[ 16 * sizeof( uint32_t ) ];
osStaticMessageQDef_t serialInputQueueControlBlock;
osMessageQId serialOutputQueueHandle;
uint8_t serialOutputQueueBuffer[ 16 * sizeof( uint32_t ) ];
osStaticMessageQDef_t serialOutputQueueControlBlock;
osMessageQId audioInputQueueHandle;
uint8_t audioInputQueueBuffer[ 8 * sizeof( uint32_t ) ];
osStaticMessageQDef_t audioInputQueueControlBlock;
osMessageQId hdlcInputQueueHandle;
uint8_t hdlcInputQueueBuffer[ 3 * sizeof( uint32_t ) ];
osStaticMessageQDef_t hdlcInputQueueControlBlock;
osMessageQId hdlcOutputQueueHandle;
uint8_t hdlcOutputQueueBuffer[ 3 * sizeof( uint32_t ) ];
osStaticMessageQDef_t hdlcOutputQueueControlBlock;
osMessageQId dacOutputQueueHandle;
uint8_t dacOutputQueueBuffer[ 128 * sizeof( uint8_t ) ];
osStaticMessageQDef_t dacOutputQueueControlBlock;
osMessageQId adcInputQueueHandle;
uint8_t adcInputQueueBuffer[ 8 * sizeof( uint32_t ) ];
osStaticMessageQDef_t adcInputQueueControlBlock;

/* USER CODE BEGIN PV */
osMutexId hardwareInitMutexHandle;

char serial_number_64[13] = {0};
char error_message[80] __attribute__((section(".bss3"))) = {0};

/* USER CODE END PV */

void SystemClock_Config(void);
static void MX_GPIO_Init(void);
static void MX_DMA_Init(void);
static void MX_ADC1_Init(void);
static void MX_CRC_Init(void);
static void MX_DAC1_Init(void);
static void MX_OPAMP1_Init(void);
static void MX_RTC_Init(void);
static void MX_TIM6_Init(void);
static void MX_TIM7_Init(void);
static void MX_USART2_UART_Init(void);
static void MX_I2C3_Init(void);
static void MX_TIM1_Init(void);
static void MX_RNG_Init(void);
static void MX_IWDG_Init(void);
void startDefaultTask(void const * argument);
extern void startIOEventTask(void const * argument);
extern void startAudioInputTask(void const * argument);
extern void startModulatorTask(void const * argument);
void encode_serial_number(void);

void HAL_TIM_MspPostInit(TIM_HandleTypeDef *htim);
                                

/* USER CODE BEGIN PFP */

/* USER CODE END PFP */

/* USER CODE BEGIN 0 */

/*
 * Same algorithm as here: https://github.com/libopencm3/libopencm3/blob/master/lib/stm32/desig.c
 */

void encode_serial_number()
{
    uint8_t *uid = (uint8_t *)UID_BASE;

    uint8_t serial[6];
    serial[0] = uid[11];
    serial[1] = uid[10] + uid[2];
    serial[2] = uid[9];
    serial[3] = uid[8] + uid[0];
    serial[4] = uid[7];
    serial[5] = uid[6];

    snprintf(
        serial_number_64,
        sizeof(serial_number_64),
        "%02X%02X%02X%02X%02X%02X",
        serial[0], serial[1], serial[2],
        serial[3], serial[4], serial[5]
    );
}

/* USER CODE END 0 */

/**
  * @brief  The application entry point.
  *
  * @retval None
  */
int main(void)
{
  /* MCU Configuration----------------------------------------------------------*/

  /* Reset of all peripherals, Initializes the Flash interface and the Systick. */
  HAL_Init();

  /* Configure the system clock */
  SystemClock_Config();

  /* Initialize all configured peripherals */
  MX_GPIO_Init();
  MX_DMA_Init();
  MX_ADC1_Init();
  MX_CRC_Init();
  MX_DAC1_Init();
  MX_OPAMP1_Init();
  MX_RTC_Init();
  MX_TIM6_Init();
  MX_TIM7_Init();
  MX_USART2_UART_Init();
  MX_I2C3_Init();
  MX_TIM1_Init();
  MX_RNG_Init();
  /* USER CODE BEGIN 2 */
#ifdef KISS_LOGGING
  printf("start\r\n");
  if (error_message[0] != 0) {
      printf(error_message);
      error_message[0] = 0;
  }
#endif
  indicate_turning_on();
  encode_serial_number();
  /* USER CODE END 2 */

  /* USER CODE BEGIN RTOS_MUTEX */
  /* add mutexes, ... */
  osMutexDef(hardwareInitMutex);
  hardwareInitMutexHandle = osMutexCreate(osMutex(hardwareInitMutex));
  osMutexWait(hardwareInitMutexHandle, osWaitForever);

  /* USER CODE END RTOS_MUTEX */

  /* USER CODE BEGIN RTOS_SEMAPHORES */
  /* add semaphores, ... */
#pragma GCC diagnostic push
#pragma GCC diagnostic ignored "-Wwrite-strings"    // cmsis-os is not const-correct.
  /* USER CODE END RTOS_SEMAPHORES */

  /* USER CODE BEGIN RTOS_TIMERS */
  /* start timers, add new ones, ... */
  /* USER CODE END RTOS_TIMERS */

  /* Create the thread(s) */
  /* definition and creation of defaultTask */
  osThreadStaticDef(defaultTask, startDefaultTask, osPriorityIdle, 0, 256, defaultTaskBuffer, &defaultTaskControlBlock);
  defaultTaskHandle = osThreadCreate(osThread(defaultTask), NULL);

  /* definition and creation of ioEventTask */
  osThreadStaticDef(ioEventTask, startIOEventTask, osPriorityLow, 0, 384, ioEventTaskBuffer, &ioEventTaskControlBlock);
  ioEventTaskHandle = osThreadCreate(osThread(ioEventTask), NULL);

  /* definition and creation of audioInputTask */
  osThreadStaticDef(audioInputTask, startAudioInputTask, osPriorityAboveNormal, 0, 512, audioInputTaskBuffer, &audioInputTaskControlBlock);
  audioInputTaskHandle = osThreadCreate(osThread(audioInputTask), NULL);

  /* definition and creation of modulatorTask */
  osThreadStaticDef(modulatorTask, startModulatorTask, osPriorityAboveNormal, 0, 384, modulatorTaskBuffer, &modulatorTaskControlBlock);
  modulatorTaskHandle = osThreadCreate(osThread(modulatorTask), NULL);

  /* USER CODE BEGIN RTOS_THREADS */
  /* add threads, ... */
  /* USER CODE END RTOS_THREADS */

  /* Create the queue(s) */
  /* definition and creation of ioEventQueue */
  osMessageQStaticDef(ioEventQueue, 16, uint32_t, ioEventQueueBuffer, &ioEventQueueControlBlock);
  ioEventQueueHandle = osMessageCreate(osMessageQ(ioEventQueue), NULL);

  /* definition and creation of serialInputQueue */
  osMessageQStaticDef(serialInputQueue, 16, uint32_t, serialInputQueueBuffer, &serialInputQueueControlBlock);
  serialInputQueueHandle = osMessageCreate(osMessageQ(serialInputQueue), NULL);

  /* definition and creation of serialOutputQueue */
  osMessageQStaticDef(serialOutputQueue, 16, uint32_t, serialOutputQueueBuffer, &serialOutputQueueControlBlock);
  serialOutputQueueHandle = osMessageCreate(osMessageQ(serialOutputQueue), NULL);

  /* definition and creation of audioInputQueue */
  osMessageQStaticDef(audioInputQueue, 8, uint32_t, audioInputQueueBuffer, &audioInputQueueControlBlock);
  audioInputQueueHandle = osMessageCreate(osMessageQ(audioInputQueue), NULL);

  /* definition and creation of hdlcInputQueue */
  osMessageQStaticDef(hdlcInputQueue, 3, uint32_t, hdlcInputQueueBuffer, &hdlcInputQueueControlBlock);
  hdlcInputQueueHandle = osMessageCreate(osMessageQ(hdlcInputQueue), NULL);

  /* definition and creation of hdlcOutputQueue */
  osMessageQStaticDef(hdlcOutputQueue, 3, uint32_t, hdlcOutputQueueBuffer, &hdlcOutputQueueControlBlock);
  hdlcOutputQueueHandle = osMessageCreate(osMessageQ(hdlcOutputQueue), NULL);

  /* definition and creation of dacOutputQueue */
  osMessageQStaticDef(dacOutputQueue, 128, uint8_t, dacOutputQueueBuffer, &dacOutputQueueControlBlock);
  dacOutputQueueHandle = osMessageCreate(osMessageQ(dacOutputQueue), NULL);

  /* definition and creation of adcInputQueue */
  osMessageQStaticDef(adcInputQueue, 3, uint32_t, adcInputQueueBuffer, &adcInputQueueControlBlock);
  adcInputQueueHandle = osMessageCreate(osMessageQ(adcInputQueue), NULL);

  /* USER CODE BEGIN RTOS_QUEUES */
  /* add queues, ... */
#pragma GCC diagnostic pop

  if (HAL_DAC_SetValue(&hdac1, DAC_CHANNEL_2, DAC_ALIGN_12B_R, 1024) != HAL_OK) Error_Handler();
  if (HAL_DAC_Start(&hdac1, DAC_CHANNEL_2) != HAL_OK) Error_Handler();
  if (HAL_OPAMP_SelfCalibrate(&hopamp1) != HAL_OK) Error_Handler();
  if (HAL_OPAMP_Start(&hopamp1) != HAL_OK) Error_Handler();
  if (HAL_ADCEx_Calibration_Start(&hadc1, ADC_SINGLE_ENDED) != HAL_OK) Error_Handler();

  FLASH_OBProgramInitTypeDef obInit = {0};
  HAL_FLASHEx_OBGetConfig(&obInit);

  if ((obInit.OptionType & OPTIONBYTE_USER) == RESET) {
    printf("FAIL: option byte init\r\n");
    Error_Handler();
  }

#if 1
  // Do not erase SRAM2 during reset.
  if ((obInit.USERConfig & FLASH_OPTR_SRAM2_RST) == RESET) {
    obInit.OptionType = OPTIONBYTE_USER;
    obInit.USERType = OB_USER_SRAM2_RST;
    obInit.USERConfig = FLASH_OPTR_SRAM2_RST;
    HAL_FLASH_OB_Unlock();
    HAL_FLASHEx_OBProgram(&obInit);
    HAL_FLASH_OB_Lock();
    HAL_FLASH_OB_Launch();
  }
#endif

#if 1
  // Enable hardware parity check on SRAM2
  if ((obInit.USERConfig & FLASH_OPTR_SRAM2_PE) == RESET) {
    obInit.OptionType = OPTIONBYTE_USER;
    obInit.USERType = OB_USER_SRAM2_PE;
    obInit.USERConfig = FLASH_OPTR_SRAM2_PE;
    HAL_FLASH_OB_Unlock();
    HAL_FLASHEx_OBProgram(&obInit);
    HAL_FLASH_OB_Lock();
    HAL_FLASH_OB_Launch();
  }
#endif

  /* USER CODE END RTOS_QUEUES */
 

  /* Start scheduler */
  osKernelStart();
  
  /* We should never get here as control is now taken by the scheduler */

  /* Infinite loop */
  /* USER CODE BEGIN WHILE */
  while (1)
  {

  /* USER CODE END WHILE */

  /* USER CODE BEGIN 3 */

  }
  /* USER CODE END 3 */

}

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
/* USER CODE BEGIN 4 */


void SysClock48()
{
    RCC_OscInitTypeDef RCC_OscInitStruct;
    RCC_ClkInitTypeDef RCC_ClkInitStruct;
    RCC_PeriphCLKInitTypeDef PeriphClkInit;

    if (HAL_RCC_GetHCLKFreq() == 48000000) return;

    INFO("Setting 48MHz SysClock.");

    taskENTER_CRITICAL();

    RCC_ClkInitStruct.ClockType = RCC_CLOCKTYPE_SYSCLK;
    RCC_ClkInitStruct.SYSCLKSource = RCC_SYSCLKSOURCE_HSI;

    if (HAL_RCC_ClockConfig(&RCC_ClkInitStruct, FLASH_LATENCY_0) != HAL_OK)
    {
      _Error_Handler(__FILE__, __LINE__);
    }

    /**Configure the Systick interrupt time
    */
    HAL_SYSTICK_Config(HAL_RCC_GetHCLKFreq()/1000);

    RCC_OscInitStruct.OscillatorType = RCC_OSCILLATORTYPE_MSI;
    RCC_OscInitStruct.MSIState = RCC_MSI_ON;
    RCC_OscInitStruct.MSICalibrationValue = RCC_MSICALIBRATION_DEFAULT;
    RCC_OscInitStruct.MSIClockRange = RCC_MSIRANGE_11;
    RCC_OscInitStruct.PLL.PLLState = RCC_PLL_ON;
    RCC_OscInitStruct.PLL.PLLSource = RCC_PLLSOURCE_MSI;
    RCC_OscInitStruct.PLL.PLLM = 4;
    RCC_OscInitStruct.PLL.PLLN = 8;
    RCC_OscInitStruct.PLL.PLLP = RCC_PLLP_DIV7;
    RCC_OscInitStruct.PLL.PLLQ = RCC_PLLQ_DIV2;
    RCC_OscInitStruct.PLL.PLLR = RCC_PLLR_DIV2;
    if (HAL_RCC_OscConfig(&RCC_OscInitStruct) != HAL_OK)
    {
      _Error_Handler(__FILE__, __LINE__);
    }

    RCC_ClkInitStruct.ClockType = RCC_CLOCKTYPE_SYSCLK;
    RCC_ClkInitStruct.SYSCLKSource = RCC_SYSCLKSOURCE_MSI;

    PeriphClkInit.PeriphClockSelection = RCC_PERIPHCLK_ADC;
    PeriphClkInit.AdcClockSelection = RCC_ADCCLKSOURCE_PLLSAI1;
    PeriphClkInit.PLLSAI1.PLLSAI1Source = RCC_PLLSOURCE_MSI;
    PeriphClkInit.PLLSAI1.PLLSAI1M = 4;
    PeriphClkInit.PLLSAI1.PLLSAI1N = 24;
    PeriphClkInit.PLLSAI1.PLLSAI1P = RCC_PLLP_DIV7;
    PeriphClkInit.PLLSAI1.PLLSAI1Q = RCC_PLLQ_DIV6;
    PeriphClkInit.PLLSAI1.PLLSAI1R = RCC_PLLR_DIV4;
    PeriphClkInit.PLLSAI1.PLLSAI1ClockOut = RCC_PLLSAI1_ADC1CLK;
    if (HAL_RCCEx_PeriphCLKConfig(&PeriphClkInit) != HAL_OK)
    {
      _Error_Handler(__FILE__, __LINE__);
    }

    if (HAL_RCC_ClockConfig(&RCC_ClkInitStruct, FLASH_LATENCY_2) != HAL_OK)
    {
      _Error_Handler(__FILE__, __LINE__);
    }

    /**Configure the Systick interrupt time
    */
    HAL_SYSTICK_Config(HAL_RCC_GetHCLKFreq()/1000);
    taskEXIT_CRITICAL();
}

void SysClock72()
{
    RCC_OscInitTypeDef RCC_OscInitStruct;
    RCC_ClkInitTypeDef RCC_ClkInitStruct;
    RCC_PeriphCLKInitTypeDef PeriphClkInit;

    if (HAL_RCC_GetHCLKFreq() == 72000000) return;

    INFO("Setting 72MHz SysClock.");

    taskENTER_CRITICAL();

    HAL_RCCEx_DisableMSIPLLMode();

    RCC_ClkInitStruct.ClockType = RCC_CLOCKTYPE_SYSCLK;
    RCC_ClkInitStruct.SYSCLKSource = RCC_SYSCLKSOURCE_HSI;

    if (HAL_RCC_ClockConfig(&RCC_ClkInitStruct, FLASH_LATENCY_0) != HAL_OK)
    {
      _Error_Handler(__FILE__, __LINE__);
    }

    RCC_OscInitStruct.OscillatorType = RCC_OSCILLATORTYPE_MSI;
    RCC_OscInitStruct.MSIState = RCC_MSI_ON;
    RCC_OscInitStruct.MSICalibrationValue = RCC_MSICALIBRATION_DEFAULT;
    RCC_OscInitStruct.MSIClockRange = RCC_MSIRANGE_11;
    RCC_OscInitStruct.PLL.PLLState = RCC_PLL_ON;
    RCC_OscInitStruct.PLL.PLLSource = RCC_PLLSOURCE_MSI;
    RCC_OscInitStruct.PLL.PLLM = 4;
    RCC_OscInitStruct.PLL.PLLN = 12;
    RCC_OscInitStruct.PLL.PLLP = RCC_PLLP_DIV7;
    RCC_OscInitStruct.PLL.PLLQ = RCC_PLLQ_DIV2;
    RCC_OscInitStruct.PLL.PLLR = RCC_PLLR_DIV2;
    if (HAL_RCC_OscConfig(&RCC_OscInitStruct) != HAL_OK)
    {
      _Error_Handler(__FILE__, __LINE__);
    }

    RCC_ClkInitStruct.ClockType = RCC_CLOCKTYPE_SYSCLK;
    RCC_ClkInitStruct.SYSCLKSource = RCC_SYSCLKSOURCE_PLLCLK;

    if (HAL_RCC_ClockConfig(&RCC_ClkInitStruct, FLASH_LATENCY_4) != HAL_OK)
    {
      _Error_Handler(__FILE__, __LINE__);
    }

    PeriphClkInit.PeriphClockSelection = RCC_PERIPHCLK_ADC;
    PeriphClkInit.AdcClockSelection = RCC_ADCCLKSOURCE_PLLSAI1;
    PeriphClkInit.PLLSAI1.PLLSAI1Source = RCC_PLLSOURCE_MSI;
    PeriphClkInit.PLLSAI1.PLLSAI1M = 4;
    PeriphClkInit.PLLSAI1.PLLSAI1N = 24;
    PeriphClkInit.PLLSAI1.PLLSAI1P = RCC_PLLP_DIV7;
    PeriphClkInit.PLLSAI1.PLLSAI1Q = RCC_PLLQ_DIV6;
    PeriphClkInit.PLLSAI1.PLLSAI1R = RCC_PLLR_DIV4;
    PeriphClkInit.PLLSAI1.PLLSAI1ClockOut = RCC_PLLSAI1_ADC1CLK;
    if (HAL_RCCEx_PeriphCLKConfig(&PeriphClkInit) != HAL_OK)
    {
      _Error_Handler(__FILE__, __LINE__);
    }

    HAL_RCCEx_EnableMSIPLLMode();

    /**Configure the Systick interrupt time
    */
    HAL_SYSTICK_Config(HAL_RCC_GetHCLKFreq()/1000);
    taskEXIT_CRITICAL();
}

void SysClock80()
{
    RCC_OscInitTypeDef RCC_OscInitStruct;
    RCC_ClkInitTypeDef RCC_ClkInitStruct;
    RCC_PeriphCLKInitTypeDef PeriphClkInit;

    if (HAL_RCC_GetHCLKFreq() == 80000000) return;

    INFO("Setting 80MHz SysClock.");

    taskENTER_CRITICAL();

    RCC_ClkInitStruct.ClockType = RCC_CLOCKTYPE_SYSCLK;
    RCC_ClkInitStruct.SYSCLKSource = RCC_SYSCLKSOURCE_HSI;

    if (HAL_RCC_ClockConfig(&RCC_ClkInitStruct, FLASH_LATENCY_0) != HAL_OK)
    {
      _Error_Handler(__FILE__, __LINE__);
    }

    RCC_OscInitStruct.OscillatorType = 0;
    RCC_OscInitStruct.PLL.PLLState = RCC_PLL_ON;
    RCC_OscInitStruct.PLL.PLLSource = RCC_PLLSOURCE_MSI;
    RCC_OscInitStruct.PLL.PLLM = 3;
    RCC_OscInitStruct.PLL.PLLN = 20;
    RCC_OscInitStruct.PLL.PLLP = RCC_PLLP_DIV7;
    RCC_OscInitStruct.PLL.PLLQ = RCC_PLLQ_DIV4;
    RCC_OscInitStruct.PLL.PLLR = RCC_PLLR_DIV4;
    if (HAL_RCC_OscConfig(&RCC_OscInitStruct) != HAL_OK)
    {
      _Error_Handler(__FILE__, __LINE__);
    }

    RCC_ClkInitStruct.ClockType = RCC_CLOCKTYPE_SYSCLK;
    RCC_ClkInitStruct.SYSCLKSource = RCC_SYSCLKSOURCE_PLLCLK;

    if (HAL_RCC_ClockConfig(&RCC_ClkInitStruct, FLASH_LATENCY_4) != HAL_OK)
    {
      _Error_Handler(__FILE__, __LINE__);
    }

    PeriphClkInit.PeriphClockSelection = RCC_PERIPHCLK_ADC;
    PeriphClkInit.AdcClockSelection = RCC_ADCCLKSOURCE_SYSCLK;
    if (HAL_RCCEx_PeriphCLKConfig(&PeriphClkInit) != HAL_OK)
    {
      _Error_Handler(__FILE__, __LINE__);
    }

    /**Configure the Systick interrupt time
    */
    HAL_SYSTICK_Config(HAL_RCC_GetHCLKFreq()/1000);
    taskEXIT_CRITICAL();
}

void SysClock4()
{
    RCC_ClkInitTypeDef RCC_ClkInitStruct;

    taskENTER_CRITICAL();

    RCC_ClkInitStruct.ClockType = RCC_CLOCKTYPE_SYSCLK;
    RCC_ClkInitStruct.SYSCLKSource = RCC_SYSCLKSOURCE_MSI;

    if (HAL_RCC_ClockConfig(&RCC_ClkInitStruct, FLASH_LATENCY_0) != HAL_OK)
    {
      _Error_Handler(__FILE__, __LINE__);
    }

    /**Configure the Systick interrupt time
    */
    HAL_SYSTICK_Config(HAL_RCC_GetHCLKFreq()/1000);

    taskEXIT_CRITICAL();
}

/* USER CODE END 4 */

/* USER CODE BEGIN Header_startDefaultTask */
/**
  * @brief  Function implementing the defaultTask thread.
  * @param  argument: Not used 
  * @retval None
  */
/* USER CODE END Header_startDefaultTask */
void startDefaultTask(void const * argument)
{

  /* USER CODE BEGIN 5 */

  /* Infinite loop */
  for(;;)
  {
    osDelay(osWaitForever);
  }
  /* USER CODE END 5 */ 
}

/**
  * @brief  Period elapsed callback in non blocking mode
  * @note   This function is called  when TIM2 interrupt took place, inside
  * HAL_TIM_IRQHandler(). It makes a direct call to HAL_IncTick() to increment
  * a global variable "uwTick" used as application time base.
  * @param  htim : TIM handle
  * @retval None
  */
void HAL_TIM_PeriodElapsedCallback(TIM_HandleTypeDef *htim)
{
  if (htim->Instance == TIM2) {
    HAL_IncTick();
  }
  /* USER CODE BEGIN Callback 1 */
  if (htim->Instance == TIM1) {
      LED_TIMER_PeriodElapsedCallback();
  }

  /* USER CODE END Callback 1 */
}

/**
  * @brief  This function is executed in case of error occurrence.
  * @param  file: The file name as string.
  * @param  line: The line in file as a number.
  * @retval None
  */
void _Error_Handler(char *file, int line)
{
  /* USER CODE BEGIN Error_Handler_Debug */
  /* User can add his own implementation to report the HAL error return state */
  snprintf(error_message, sizeof(error_message), "Error: %s:%d\r\n", file, line);
  error_message[sizeof(error_message) - 1] = 0;

  NVIC_SystemReset();
  /* USER CODE END Error_Handler_Debug */
}

#ifdef  USE_FULL_ASSERT
/**
  * @brief  Reports the name of the source file and the source line number
  *         where the assert_param error has occurred.
  * @param  file: pointer to the source file name
  * @param  line: assert_param error line source number
  * @retval None
  */
void assert_failed(uint8_t* file, uint32_t line)
{ 
  /* USER CODE BEGIN 6 */
    _Error_Handler(file, line);
  /* User can add his own implementation to report the file name and line number,
     tex: printf("Wrong parameters value: file %s on line %d\r\n", file, line) */
  /* USER CODE END 6 */
}
#endif /* USE_FULL_ASSERT */

void vApplicationStackOverflowHook(TaskHandle_t xTask, signed char *pcTaskName)
{
    snprintf(error_message, sizeof(error_message), "stack overflow %s", pcTaskName);
    while (1);
}

/**
  * @}
  */

/**
  * @}
  */

/************************ (C) COPYRIGHT STMicroelectronics *****END OF FILE****/

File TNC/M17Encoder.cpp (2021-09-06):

// Copyright 2015-2021 Mobilinkd LLC <rob@mobilinkd.com>
// All rights reserved.

#include "M17Encoder.h"
#include "HdlcFrame.hpp"
#include "Modulator.hpp"
#include "ModulatorTask.hpp"
#include "KissHardware.hpp"
#include "DCD.h"
#include "Golay24.h"
#include "Trellis.h"
#include "M17.h"
#include "AudioInput.hpp"

#include "stm32l4xx_hal.h"

#include <algorithm>
#include <array>
#include <cstdint>

static uint32_t encoderTaskBuffer[ 256 ];
static osStaticThreadDef_t encoderTaskControlBlock;
static uint8_t m17EncoderInputQueueBuffer[ 3 * sizeof( uint32_t ) ];
static osStaticMessageQDef_t m17EncoderInputQueueControlBlock;
static uint8_t m17EncoderOutputQueueBuffer[ 3 * sizeof( uint32_t ) ];
static osStaticMessageQDef_t m17EncoderOutputQueueControlBlock;

static osMessageQId m17EncoderInputQueueHandle;
static osMessageQId m17EncoderOutputQueueHandle;

extern RNG_HandleTypeDef hrng;
extern IWDG_HandleTypeDef hiwdg;

namespace mobilinkd
{

constexpr int8_t bits_to_symbol(uint8_t bits)
{
    switch (bits)
    {
    case 0: return 1;
    case 1: return 3;
    case 2: return -1;
    case 3: return -3;
    }
    return 0;
}

M17Encoder::M17Encoder(osMessageQId input)
: input_queue(input)
{
    #pragma GCC diagnostic push
    #pragma GCC diagnostic ignored "-Wwrite-strings"    // cmsis-os is not const-correct.

    osMessageQStaticDef(m17EncoderInputQueue, 3, uint32_t, m17EncoderInputQueueBuffer, &m17EncoderInputQueueControlBlock);
    m17EncoderInputQueueHandle = osMessageCreate(osMessageQ(m17EncoderInputQueue), NULL);
    osMessageQStaticDef(m17EncoderOutputQueue, 3, uint32_t, m17EncoderOutputQueueBuffer, &m17EncoderOutputQueueControlBlock);
    m17EncoderOutputQueueHandle = osMessageCreate(osMessageQ(m17EncoderOutputQueue), NULL);
    osThreadStaticDef(encoderTask, M17Encoder::encoderTask, osPriorityNormal,
        0, 256, encoderTaskBuffer, &encoderTaskControlBlock);

    #pragma GCC diagnostic pop

    encoderTaskHandle = osThreadCreate(osThread(encoderTask), this);
    osThreadSuspend(encoderTaskHandle);
    src.fill(0xff);
    dest.fill(0xff);
}

M17Encoder::~M17Encoder() {}

void M17Encoder::run()
{
    using tnc::hdlc::IoFrame;
    using tnc::hdlc::release;

    state = State::IDLE;

    osThreadResume(encoderTaskHandle);

    auto start = osKernelSysTick();
    int32_t delay_ms = 0;

    state = State::IDLE;

    while (state != State::INACTIVE)
    {
        osEvent evt = osMessageGet(input_queue, osWaitForever);
        if (evt.status == osEventMessage)
        {
            // Changing encoders when nullptr is received.
            if (evt.value.p == nullptr)
            {
                state = State::INACTIVE;
                break;
            }
            auto frame = static_cast<IoFrame*>(evt.value.p);
            switch (frame->source())
            {
            case 0x00: // Basic packet data
                delay_ms = ((frame->size() / 25) + 1) * 40;
                start = osKernelSysTick();
                process_packet(frame, FrameType::BASIC_PACKET);
                break;
            case 0x10: // Encapsulated packet data
                delay_ms = (frame->size() / 25) * 40;
                start = osKernelSysTick();
                process_packet(frame, FrameType::FULL_PACKET);
                break;
            case 0x20: // Voice stream
                if (back2back) delay_ms += 40;
                else delay_ms = 80 + tnc::kiss::settings().txdelay * 10;
                start = osKernelSysTick();
                process_stream(frame, FrameType::VOICE_STREAM);
                break;
            default:
                release(frame);
                // ignore it
            }

            evt = osMessagePeek(input_queue, delay_ms);
            // auto num_msgs = osMessageWaiting(input_queue);
            back2back = (evt.status == osEventMessage);
            if (!back2back)
            {
                if (state != State::IDLE)
                {
                    WARN("Timed out waiting for packet (%lums).", delay_ms);
                    size_t counter = 5;
                    do {
                        send_link_setup();
                        evt = osMessagePeek(input_queue, 40);
                    } while (evt.status != osEventMessage && --counter != 0);

                    if (evt.status != osEventMessage) {
                        state = State::IDLE;
                        WARN("Timed out waiting for packet.");
                    }
                }
                delay_ms = 0;
            }
            else
            {
                int duration = osKernelSysTick() - start;
                if (duration >= delay_ms) delay_ms = 0;
                else delay_ms -= duration;
                INFO("Slack time = %lums", delay_ms);
            }
        }
    }

    osThreadSuspend(encoderTaskHandle);
}

/**
 *
 * @param frame is the frame to transmit. Ownership has been transferred
 *  and this function is responsible for either transferring ownership
 *  downstream or releasing it.
 * @param type is whether this is a basic packet or encapsulated packet.
 */
void M17Encoder::process_packet(tnc::hdlc::IoFrame* frame, FrameType type)
{
    using namespace mobilinkd::tnc::kiss;
    using tnc::hdlc::release;

    switch (state)
    {
    case State::IDLE:
        if (!back2back) // Do CSMA and preamble?
        {
            if (!settings().duplex) // Only do CSMA in half-duplex mode.
            {
                if (!do_csma())     // Wait for channel to clear.
                {
                    release(frame);
                    WARN("Could not send frame; channel busy.");
                    return;
                }
            }

            send_preamble();
        }
        create_link_setup(frame, type);
        send_link_setup();
        if (type == FrameType::BASIC_PACKET)
            send_basic_packet(frame);
        else
            send_full_packet(frame);
        break;
    case State::ACTIVE:
        // Protocol violation.
        WARN("Protocol violation -- packet received while stream active.");
        state = State::IDLE;
        break;
    default:
        ERROR("M17 encoder bad state");
    }
    release(frame);
}
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

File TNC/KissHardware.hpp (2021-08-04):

// Copyright 2015-2021 Mobilinkd LLC <rob@mobilinkd.com>
// All rights reserved.

#pragma once

#include "Log.h"
#include "HdlcFrame.hpp"
#include "AFSKTestTone.hpp"
#include "main.h"

#include <cstdint>
#include <cstring>
#include <array>

extern "C" void updatePtt(void);

namespace mobilinkd { namespace tnc { namespace kiss {

extern const char FIRMWARE_VERSION[];
extern const char HARDWARE_VERSION[];

AFSKTestTone& getAFSKTestTone();

namespace hardware {

/**
 * This indicates the API version of the device.  API versions are used to
 * indicate to the user that the config app may need to be upgraded because
 * the device is using a newer configuration API.
 *
 * The minor version should be updated whenever the API is extended (new
 * GET/SET or CAP types added.
 *
 * The major version should be updated whenever non-backwards compatible
 * changes to the API are made.
 */
constexpr const uint16_t KISS_API_VERSION = 0x0202;

constexpr const uint16_t CAP_DCD = 0x0100;
constexpr const uint16_t CAP_SQUELCH = 0x0200;
constexpr const uint16_t CAP_INPUT_ATTEN = 0x0400;
constexpr const uint16_t CAP_FIRMWARE_VERSION = 0x0800;
constexpr const uint16_t CAP_BATTERY_LEVEL = 0x1000;
constexpr const uint16_t CAP_BT_CONN_TRACK = 0x2000;
constexpr const uint16_t CAP_BT_NAME_CHANGE = 0x4000;
constexpr const uint16_t CAP_BT_PIN_CHANGE = 0x8000;
constexpr const uint16_t CAP_VERBOSE_ERROR = 0x0001;
constexpr const uint16_t CAP_EEPROM_SAVE = 0x0002;
constexpr const uint16_t CAP_ADJUST_INPUT = 0x0004; // Auto-adjust input levels.
constexpr const uint16_t CAP_DFU_FIRMWARE = 0x0008; // DFU firmware style.

constexpr const uint8_t SAVE = 0; // Save settings to EEPROM.
constexpr const uint8_t SET_OUTPUT_GAIN = 1;
constexpr const uint8_t SET_INPUT_GAIN = 2;
constexpr const uint8_t SET_SQUELCH_LEVEL = 3;      // deprecated.
constexpr const uint8_t POLL_INPUT_LEVEL = 4;
constexpr const uint8_t STREAM_INPUT_LEVEL = 5;
constexpr const uint8_t GET_BATTERY_LEVEL = 6;
constexpr const uint8_t SEND_MARK = 7;
constexpr const uint8_t SEND_SPACE = 8;
constexpr const uint8_t SEND_BOTH = 9;
constexpr const uint8_t STOP_TX = 10;
constexpr const uint8_t RESET = 11;
constexpr const uint8_t GET_OUTPUT_GAIN = 12;
constexpr const uint8_t GET_INPUT_GAIN = 13;
constexpr const uint8_t GET_SQUELCH_LEVEL = 14;
constexpr const uint8_t STREAM_DCD_VALUE = 15;

constexpr const uint8_t SET_VERBOSITY = 16;
constexpr const uint8_t GET_VERBOSITY = 17;

constexpr const uint8_t SET_INPUT_OFFSET = 18;
constexpr const uint8_t GET_INPUT_OFFSET = 19;
constexpr const uint8_t SET_OUTPUT_OFFSET = 20;
constexpr const uint8_t GET_OUTPUT_OFFSET = 21;
constexpr const uint8_t SET_LOWPASS_FREQ = 22;
constexpr const uint8_t GET_LOWPASS_FREQ = 23;
constexpr const uint8_t SET_INPUT_TWIST = 24;
constexpr const uint8_t GET_INPUT_TWIST = 25;
constexpr const uint8_t SET_OUTPUT_TWIST = 26;
constexpr const uint8_t GET_OUTPUT_TWIST = 27;

constexpr const uint8_t STREAM_RAW_INPUT = 28;
constexpr const uint8_t STREAM_AMPLIFIED_INPUT = 29;
constexpr const uint8_t STREAM_FILTERED_INPUT = 30;
constexpr const uint8_t STREAM_OUTPUT = 31;

constexpr const uint8_t OK = 32;                  // Acknowledge SET commands.

constexpr const uint8_t GET_TXDELAY = 33;
constexpr const uint8_t GET_PERSIST = 34;
constexpr const uint8_t GET_TIMESLOT = 35;
constexpr const uint8_t GET_TXTAIL = 36;
constexpr const uint8_t GET_DUPLEX = 37;

constexpr const uint8_t GET_FIRMWARE_VERSION = 40;
constexpr const uint8_t GET_HARDWARE_VERSION = 41;
constexpr const uint8_t SAVE_EEPROM_SETTINGS = 42;
constexpr const uint8_t ADJUST_INPUT_LEVELS = 43;       // Auto-adjust levels.
constexpr const uint8_t POLL_INPUT_TWIST = 44;
constexpr const uint8_t STREAM_AVG_INPUT_TWIST = 45;
constexpr const uint8_t STREAM_INPUT_TWIST = 46;
constexpr const uint8_t GET_SERIAL_NUMBER = 47;
constexpr const uint8_t GET_MAC_ADDRESS = 48;
constexpr const uint8_t GET_DATETIME = 49;
constexpr const uint8_t SET_DATETIME = 50;
constexpr const uint8_t GET_ERROR_MSG = 51;
constexpr const uint8_t GET_SNR = 52;
constexpr const uint8_t GET_BER = 53;

constexpr const uint8_t SET_BLUETOOTH_NAME = 65;
constexpr const uint8_t GET_BLUETOOTH_NAME = 66;
constexpr const uint8_t SET_BLUETOOTH_PIN = 67; // Danger Will Robinson.
constexpr const uint8_t GET_BLUETOOTH_PIN = 68;
constexpr const uint8_t SET_BT_CONN_TRACK = 69; // Bluetooth connection tracking
constexpr const uint8_t GET_BT_CONN_TRACK = 70; // Bluetooth connection tracking
constexpr const uint8_t SET_BT_MAJOR_CLASS = 71; // Bluetooth Major Class
constexpr const uint8_t GET_BT_MAJOR_CLASS = 72; // Bluetooth Major Class
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

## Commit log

2018-07-29 Initial STM32CubeMX code generation.
2018-07-30 Add TNC code, openocd configs, etc.
    [stlink-tnc5.cfg, stm32l4x.cfg]
2018-08-06 Move some pins around, use LED3, and name the AUDIO_IN pin. Initialize DAC, Op Amp and ADC in main(). Increase ADC clock to 80MHz and enable 16x oversampling. Increase sample time to 6.5 cycles. Supp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
    [AudioInput.cpp, AudioLevel.cpp, GPIO.hpp]
2018-08-06 Make it save to use LEDs in ISR.
2018-08-06 Fix defect in L4 HAL version 1.12.0 LL ADC code that misconfigures the ADC channel.
2018-08-06 Fix & enable I2C EEPROM support.
    [AudioLevel.cpp, KissHardware.cpp]
2018-08-12 Fix broken critical section handling when toggling LEDs.
2018-08-14 Cannot use TRACESWO on Nucleo32 boards.
2018-08-14 Add note about fixing ADC LL driver to README.
2019-06-23 Massive update to get the NucleoTNC firmware up to date with the TNC3. Mostly improvements to the moduleator and demodulator sections. Fix EEPROM read/write. Update version number to 1.0.0.
    [AudioInput.cpp, AudioLevel.cpp]
2019-06-23 Add KiCAD files and build instructions.
    [Nucleo32TNC.kicad_pcb, Nucleo32TNC.sch]
2019-06-24 Schematic not displaying.
2020-05-29 Add NucleoTNC Rev B PCB, spacer and enclosure panels.
    [BackPanel.kicad_pcb, BackPanel.sch, CUI_DEVICES_SJ-43515TS.step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]
2020-06-01 Update footprints in schematic, and values for J1 and SW1 in schematic and PCB. Add an interactive BOM. Update the README.
    [Nucleo32TNC.kicad_pcb, Nucleo32TNC.sch]
2021-01-03 Update documentation and make one small part change to improve 9600 baud and M17 decode performance.
    [Nucleo32TNC.sch]
2021-01-23 Move demodulator control from encoder to modulator. Fix stream encoding. Improve stream buffering.
    [M17Encoder.cpp]
2021-02-22 Sync NucleoTNC firmware with TNC3 v2.1.8 codebase. Upgrade compiler to GCC 10.2. Upgrade to C++20 for std::span. Changes to reduce stack utilization. Reduce jitter by adjusting clocks & interrupt pri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
    [KissHardware.cpp, KissHardware.hpp, M17Encoder.cpp]
2021-06-20 Statically allocate buffers needed for serial thread and queue. Limit frame churn.
2021-06-21 Make FIR filter input and output buffers global to reduce RAM consumption.
2021-06-21 Fix memory leak (frame buffers) in M17 packet handling.
    [M17Encoder.cpp]
2021-06-21 Add missing function declaration for SysClock72().
    [main.h]
2021-06-22 Fix empty body warning when not logging.
    [M17Encoder.cpp]
2021-06-22 Update clock trees. Update 1200 baud modem to run at 48MHz, same as TNC3. Update 9600 baud modem to run at 72MHz instead of 80MHz. Fixes 9600 baud mode broken by M17 changes.
    [Fsk9600Modulator.cpp, main.c]
2021-06-22 Fix peripheral clock tree.
    [main.c]
2021-06-23 Simplify & correct clock trees.
    [main.c]
2021-06-26 Set I2C timing to 400kHz for EEPROM access.
2021-07-01 Simplify FIR filter code.
2021-07-01 Update firmware to use new stream frame format. Update version to 2.3.0.
2021-07-09 Add support for frame resizing. Handle old stream frame type in encoder.
2021-10-26 Fix M17 RX reverse polarity.
    [KissHardware.cpp]
2022-01-23 Add 8 and 11 symbol RRC filters to M17 demod.
2022-01-23 Add reset() function to IIR filter.
2022-01-23 Use an 8-symbol length FIR filter for symbol interpolation.
2022-01-23 Add Kalman filter code. This adds a dependency on Blaze and requires that exceptions be enabled.
2022-01-23 Add symbol slope integrator code (currently unused).
2022-01-23 Use EOT sync word for end of stream rather than EOS bit. Use only sync word and Kalman filter for clock recovery. Simplify some of the state transistions. Reduce DCD limits since we can follow symbol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
2022-02-20 Add BOM for rev C PCB.
2022-05-29 Update to version 2.4.4. Clock recovery improvements. Update the sample index more frequently to reduce EVM. Re-wrote the symbol deviation, offset, EVM code. More code comments.

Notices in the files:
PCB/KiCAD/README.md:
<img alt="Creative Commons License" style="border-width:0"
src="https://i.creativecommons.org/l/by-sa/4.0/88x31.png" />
